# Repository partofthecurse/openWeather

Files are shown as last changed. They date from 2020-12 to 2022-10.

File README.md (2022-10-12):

# openWeather
Open Source Weather Station that also looks quite nice.
Concept:
We are requesting Temperature and Weather ID with an openWeatherMap API Call . Weather is Displayed through Neopixel LEDs under a PMMA-Screen with engraved Icons. Temperature is resembled with LED Colour.

Features:
    - MQTT
    - ArduinoOTA
    - WifiManager & Captive Portal

Parts needed:

    - ESP8266 or ESP32 Board, alternatively arduino nano with wifi shield will do as well but not coded here
    - Optional: DHT22 or DHT11 Sensor to measure Indoor Temp and Humidity
    - 4x WS2812 (aka NeoPixel) LED

Solder the 4 LEDs into a tiny LED Strip and connect to Dev Board:

    Board LED   LED   LED   LED
    3V3 - VCC - VCC - VCC - VCC
    GND - GND - GND - GND - GND
    D8 -  I/0 - I/O - I/O - I

Connect DHT22 / DHT11 to

    Board DHT
    3V3 - +
    GND - -
    D4  - OUT

Pixel-ID Icon reference (take care when assembling or switch in the code)

    0 - clear sky
    1 - cloudy
    2 - rainy
    3 - snow

Outdoortemperature & Colours:

    > 30°C - Red
    > 21°C - Warm yellow
    < 18°C - Light blue
    < 00°C - Blue
    Thunderstorm: Yellow
    Fog: White

    Red: error
    green: connecting

Optional: Send the measured DHT Data to an MQTT Broker (topics are customizable in captive portal)
    
    receive Data:
    temperature: stat/openWeather/Temperatur
    Humidity: stat/openWeather/Feuchtigkeit
    HeatIndex: stat/openWeather/HeatIndex
    
    controll openWeather:
    light on: cmnd/openWeather/power - payload on
    light off: cmnd/openWeather/power - payload off
    switch to party mode: cmnd/openWeather/state - PixelParty1 or PixelParty2
    
    upon receiving a command it sends back on stat/openWeather/power and stat/openWeather/state which mode it is in.
    
Dependencies:

    PubSubClient
    ArduinoJson
    ESP8266 Libs
    ESP32 Libs
    DHT Sensor library for ESPx
    WifiManager
    LittleFS
    
Now with WifiManager and OTA Updates (PW: admin)

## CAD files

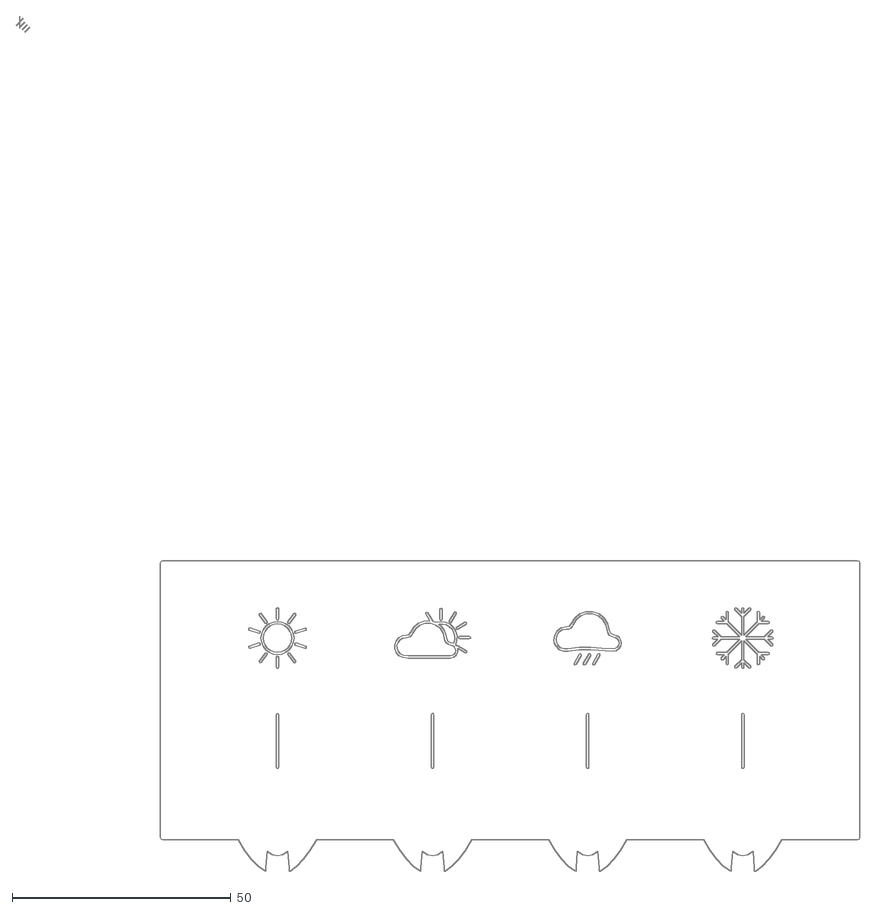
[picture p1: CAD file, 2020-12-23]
DXF/Scheibe1.DXF
192.7 x 195.3

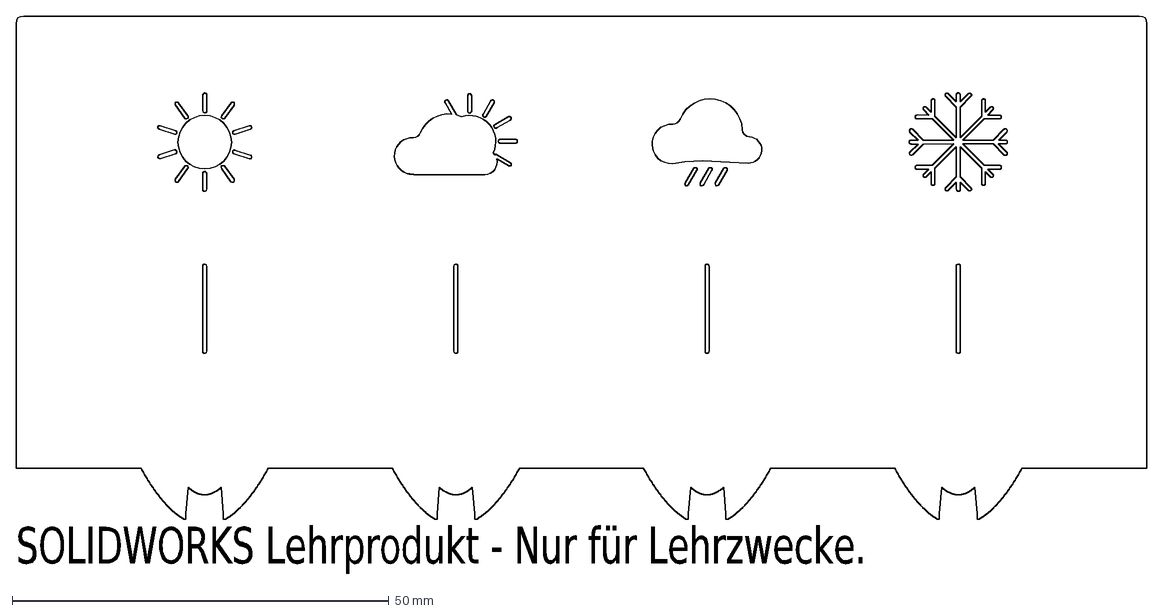
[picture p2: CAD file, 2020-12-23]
DXF/Scheibe.DXF
SOLIDWORKS Lehrprodukt - Nur für Lehrzwecke.

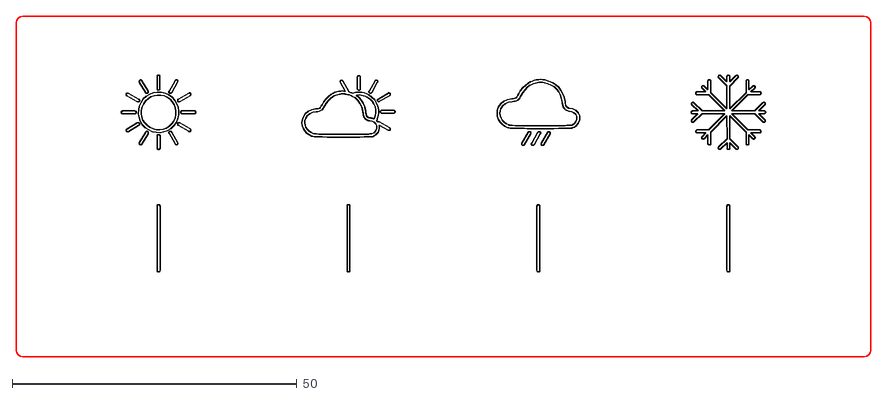
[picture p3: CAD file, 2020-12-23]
DXF/ICON_Design.dxf
150.0 x 59.8

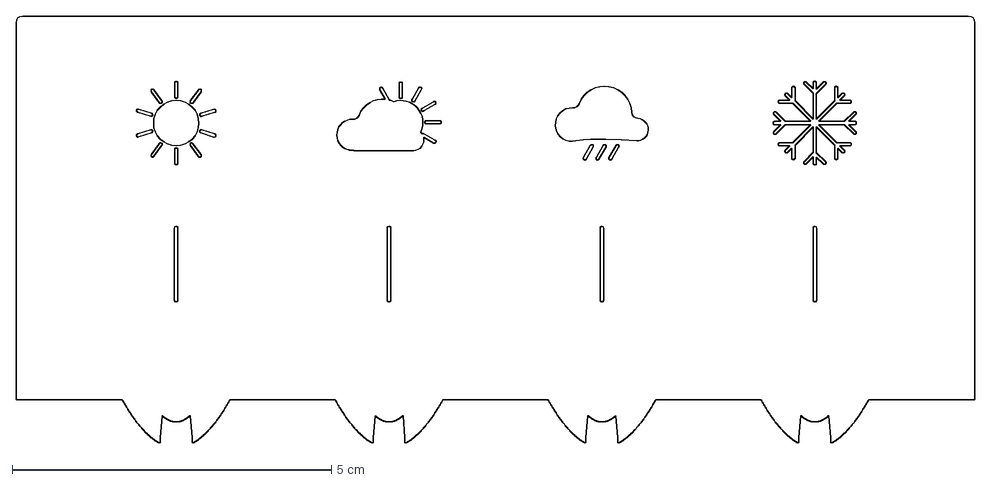
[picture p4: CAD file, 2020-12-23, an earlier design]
DXF/Scheibe v1.dxf
15.0 x 6.68 cm

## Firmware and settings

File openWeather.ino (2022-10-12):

/* Open Weather - the open source weatherbeacon that also looks good.
    We connect to your home wifi and send a http request to open weathermap every hour to update the free 3 hour forecast.
    depending on the weather-id (https://openweathermap.org/weather-conditions#Weather-Condition-Codes-2) another led will light up
    in a predefined colour to resemble weather and temperature and hightlight the respective icon.

    See Full documentation on https://daniel-strohbach.de/diy-esp8266-wetterstation

    Parts needed:
    - ESP8266 or ESP32 Board, alternatively arduino nano with wifi shield will do as well but not coded here
    - Optional: DHT22 or DHT11 Sensor to measure Indoor Temp and Humidity
    - 4x WS2812 (aka NeoPixel) LED

    Solder the 4 LEDs into a tiny LED Strip and connect to Dev Board:
    Board LED   LED   LED   LED
    3V3 - VCC - VCC - VCC - VCC
    GND - GND - GND - GND - GND
    D8 -  I/0 - I/O - I/O - I

    Connect DHT22 / DHT11 to
    Board DHT
    3V3 - +
    GND - -
    D4  - OUT

    Pixel-ID Icon reference (take care when assembling or switch in the code

    0 - clear sky
    1 - cloudy
    2 - rainy
    3 - snow

    Outdoortemperature & Colours:
    > 30°C - Red
    > 21°C - Warm yellow
    < 18°C - Light blue
    < 00°C - Blue
    Thunderstorm: Yellow
    Fog: White

    Red: Wifi related error
    green: connecting

    Optional: Send the measured DHT Data to an MQTT Broker (topics are customizable within captive portal)
    receive Data:
    temperature: stat/openWeather/Temperatur
    Humidity: stat/openWeather/Feuchtigkeit
    HeatIndex: stat/openWeather/HeatIndex
    
    control openWeather:
    light on: cmnd/openWeather/power - payload on
    light off: cmnd/openWeather/power - payload off
    switch to party mode: cmnd/openWeather/state - PixelParty1 or PixelParty2
    
    upon receiving a command it sends back on stat/openWeather/power and stat/openWeather/state which mode it is in.
    
    Dependencies:
    PubSubClient
    ArduinoJson
    ESP8266 Libs
    ESP32 Libs
    DHT Sensor library for ESPx
    WifiManager
    LittleFS

    Now with Wifi Manager or HardCoded Wifi credentials optional.
    Thanks to https://github.com/CurlyWurly-1/ESP8266-WIFIMANAGER-MQTT/blob/master/MQTT_with_WiFiManager.ino
    
    Now with OTA Update via ArduinoOTA

    Made By Daniel Strohbach www.daniel-strohbach.de/
*/

//--- USER CONFIG ---

//Do you want to use MQTT?
#define USEMQTT

//Do you want to use Managed WIFI or Hardcoded Wifi?
#define USEWIFIMANAGER
// #define USEWIFI //if so, do not forget to enter your credentials in line 116/117

//Do you want to use DHT?
#define USEDHT

//Do you use ESP8266 or ESP32? -> Switch to the correct one, if needed
#define ESP8266

//Do you want to use Serial Monitor for Debugging?
#define DEBUGING

//Which Board?

#ifdef ESP8266
#include <ESP8266WiFi.h>        // for WiFi functionality
#include <ESP8266HTTPClient.h>  //for the API-Request
#include <ESP8266WebServer.h>
//#include "SPIFFS.h"
#include <LittleFS.h>  //for ESP82
#define SPIFFS LittleFS
#endif

#ifdef ESP32
#include <WiFi.h>  //in case you are on esp32 we switch to this line
#include <HTTPClient.h>
#include <ESP32WebServer.h>
//#include "SPIFFS.h"
#include <LITTLEFS.h>  //for ESP32
#define SPIFFS LITTLEFS
#endif

//WIfi-Manager and Captive Portal
#include <DNSServer.h>
#include <WiFiManager.h>  // https://github.com/tzapu/WiFiManager

//OTA Updates
#include <ESP8266mDNS.h>
#include <WiFiUdp.h>
#include <ArduinoOTA.h>

//Colours and Position
int GcolourR, GcolourG, GcolourB, Gposition;

// Please Change to your WIFI-Credentials
#ifdef USEWIFI
const char* ssid = "SSID";
const char* password = "PW";
#endif

//What citiy you want to receive the weather from?
const char* city = "Munich,de";  //City and Country like this Oldenburg,de

//Here please add your Open Weathermap API Key from https://home.openweathermap.org/api_keys
#define openWeatherAPI "API"

//What units do you use?
const char* unitSystem = "metric";

#include <ArduinoJson.h>  //JSON String conversion for Open Weathermap API Request and WifiManager

// We use Neopixel to Control the WS2812. In my build i use a node mcu esp8266 and pin d8 to drive the pixels
#include <Adafruit_NeoPixel.h>

#define LEDPIN D8    //neopixels to pin d8
#define NUMPIXELS 4  // My Vesion has 4 Pixels

Adafruit_NeoPixel pixels(NUMPIXELS, LEDPIN, NEO_GRB + NEO_KHZ800);  //build the neopixel constructor

#ifdef USEWIFIMANAGER
WiFiManager wifiManager;
#endif

//--- MQTT ---
#ifdef USEMQTT
#include <PubSubClient.h>

bool mqttConnected = false;

//define your default values here, if there are different values in config.json, they are overwritten.
#define mqttServer "192.168.178.XX"
#define mqttUsername "mqtt-user"
#define mqttPassword "PW"
#define mqttPort "1883"
#define mqttDeviceID "openWeather"

//i use something quite similar to tasmota, but feel free to change
#define subTopic "cmnd/openWeather/state"
#define subTopic1 "cmnd/openWeather/power"
#define resTopic "stat/openWeather/state"
#define resTopic1 "stat/openWeather/power"
#define temperatureTopic "stat/openWeather/Temperatur"
#define humidityTopic "stat/openWeather/Feuchtigkeit"
#define heatIndexTopic "stat/openWeather/HeatIndex"

unsigned long lastMsg = 0;

WiFiClient openWeather;
PubSubClient MQTTclient(openWeather);
void callback(char* topic, byte* message, unsigned int length);
#endif

//--- DHT ---
#ifdef USEDHT
#include "DHTesp.h"
#define DHTPIN D4
DHTesp dht;

//--- Global Variables for Sensor storage--- // not elegant, but it works :)
float temperature, humidity, heatIndex;
#endif

//--- Timer Stuff ---
#ifdef USEDHT
unsigned long previousMillisMes;             //previous timer time
const unsigned long measureIntervall = 500;  //update sensor every 500ms
#endif

#ifdef USEMQTT
unsigned long previousMillisPub;              //for timer to publish to mqtt broker
const unsigned long publishIntervall = 5000;  //publish mqtt every 5 sekonds
#endif

unsigned long previousMillisReq;                 //for timer to request the weather data from openWeathermap
const unsigned long requestIntervall = 3600000;  //drive http request every hour

int modus = 0;          //for different control modes
bool firstloop = true;  //well, self explanatory

//flag for saving data
#ifdef USEWIFIMANAGER
bool shouldSaveConfig = false;
#endif

//---------------------------------------------- ARDUINO SETUP ------------------------------------------------------

void setup() {
  //Begin serial connection
#ifdef DEBUGING
  Serial.begin(9600);
  Serial.println();
  Serial.println();

  //Welcome to Serial Monitor
  Serial.println("openWeather: Erfasse Wetter, Temperatur, Feuchtigkeit on: ");
  String thisBoard = ARDUINO_BOARD;
  Serial.println(thisBoard);
#endif

  //--Neopixel
  pixels.begin();  // INITIALIZE NeoPixel strip object
  pixels.clear();  // Set all pixel colors to 'off'

#ifdef USEWIFIMANAGER
  //Wifi-Manager
  setup_wifimanager();
#endif

#ifdef USEWIFI
  //--Wifi
  setup_wifi();
#endif

  //--MQTT
#ifdef USEMQTT
  MQTTclient.setServer(mqttServer, atoi(mqttPort));
#ifdef DEBUGING
  Serial.println("MQTT Setup: Server and Port are Set to: ");
#endif
  MQTTclient.setCallback(callback);
#ifdef DEBUGING
  Serial.println("MQTT Setup: callback function set");
#endif
  MQTTclient.subscribe(subTopic);
#ifdef DEBUGING
  Serial.println("MQTT Setup: subscribed to subTopic");
#endif
  MQTTclient.setKeepAlive(90);
#ifdef DEBUGING
  Serial.println("MQTT Setup: set KeepAlive to 90");
#endif
  reconnect();  //establish connection to mqtt server
#ifdef DEBUGING
  Serial.println("MQTT Setup: finished");
#endif
#endif

  //--DHT
#ifdef USEDHT
  dht.setup(DHTPIN, DHTesp::DHT22);  // Connect DHT sensor to GPIO 17
#ifdef DEBUGING
  Serial.println("DHT Setup: Sensor connected to GPIO");
#endif
#endif

  //--OTA UPDATES

  // Port defaults to 8266
  // ArduinoOTA.setPort(8266);

  // Hostname defaults to esp8266-[ChipID]
  ArduinoOTA.setHostname("openWeather");

  // No authentication by default
  ArduinoOTA.setPassword("admin");

  // Password can be set with it's md5 value as well
  // MD5(admin) = 21232f297a57a5a743894a0e4a801fc3
  // ArduinoOTA.setPasswordHash("21232f297a57a5a743894a0e4a801fc3");

  ArduinoOTA.onStart([]() {
    String type;
    if (ArduinoOTA.getCommand() == U_FLASH) {
      type = "sketch";
    } else {  // U_FS
      type = "filesystem";
    }

// NOTE: if updating FS this would be the place to unmount FS using FS.end()
#ifdef DEBUGING
    Serial.println("Start updating " + type);
#endif
  });
  ArduinoOTA.onEnd([]() {
#ifdef DEBUGING
    Serial.println("\nEnd");
#endif
  });
  ArduinoOTA.onProgress([](unsigned int progress, unsigned int total) {
#ifdef DEBUGING
    Serial.printf("Progress: %u%%\r", (progress / (total / 100)));
#endif
  });
  ArduinoOTA.onError([](ota_error_t error) {
#ifdef DEBUGING
    Serial.printf("Error[%u]: ", error);
    if (error == OTA_AUTH_ERROR) {
      Serial.println("Auth Failed");
    } else if (error == OTA_BEGIN_ERROR) {
      Serial.println("Begin Failed");
    } else if (error == OTA_CONNECT_ERROR) {
      Serial.println("Connect Failed");
    } else if (error == OTA_RECEIVE_ERROR) {
      Serial.println("Receive Failed");
    } else if (error == OTA_END_ERROR) {
      Serial.println("End Failed");
    }
#endif
  });
  ArduinoOTA.begin();
}  // end of void setup

//--- ARDUINO LOOP ---

void loop() {

#ifdef DEBUGING
  Serial.println("void loop: Started... ");
  Serial.print("Wifi Connected: ");

  if ((WiFi.status() == WL_CONNECTED)) {
    Serial.println("true");
  } else {
    Serial.println("false");
  }
#ifdef USEMQTT
  Serial.print("MQTT Connected: ");
  if ((MQTTclient.state() == 0)) {
    Serial.println("true");
  } else {
    Serial.println("false");
  }
#endif
#endif

  ArduinoOTA.handle();  //handles the ota update stuff

//if mqtt is not connected, try again
#ifdef USEMQTT
  if ((!MQTTclient.state() == 0)) {
    reconnect();
  }
#endif

//what mode are we in? (light on or off, party mode or not)
#ifdef DEBUGING
  Serial.print("void loop: Modus: ");
  Serial.println(modus);
#endif

  //if we are in the first loop, we already want to fetch the weather data, afterwards only every hour
  if (firstloop) {
    getWeather();
    firstloop = false;
#ifdef DEBUGING
    Serial.print("first loop: fetching weather data: ");
#endif
  }

  //get Weatherdata every hour (or what you did custom)
  if (millis() - previousMillisReq >= requestIntervall) {
    previousMillisReq = millis();
    if (modus == 0) {
      getWeather();
#ifdef DEBUGING
      Serial.print("timer: fetching weather data: ");
#endif
    }
  }

//read sensor data
#ifdef USEDHT
  //read sensor
  if (millis() - previousMillisMes >= measureIntervall) {
    previousMillisMes = millis();
    getDHT();
#ifdef DEBUGING
    Serial.print("timer: fetching dht sensor data: ");
#endif
  }
#endif

//send the data to mqtt broker
#ifdef USEMQTT
  //publish to MQTT Broker
  if (millis() - previousMillisPub >= publishIntervall) {
    previousMillisPub = millis();
    publishMQTT();
#ifdef DEBUGING
    Serial.print("timer: sending mqtt data: ");
#endif
  }
#endif

//keep mqtt connection alive
#ifdef USEMQTT
  if (MQTTclient.loop()) {
#ifdef DEBUGING
    Serial.println("MQTT Client.loop called successfull");
#endif
  } else {
#ifdef DEBUGING
    Serial.println("MQTT Client.loop call failed");
#endif
  }
#endif

  //some remote control for different uses - maybe switch case is better?!
  if (modus == 1) {
    pixelParty();
  }

  if (modus == 2) {
    rainbowFade(3, 3, 1);
  }

  if (modus == 3) {  //weather icon is off
    pixels.clear();
    pixels.show();
  }

  if (modus == 0) {  // weather icon is on again
    pixels.clear();
    showWeather();
  }

}  //end of void loop

//--- CUSTOM CLASSES ---

//--callback notifying us of the need to save config
void saveConfigCallback() {
#ifdef DEBUGING
  Serial.println("Should save config");
#endif
  shouldSaveConfig = true;
}

//------------------------Wifi-Manager-----------------------------
#ifdef USEWIFIMANAGER
void setup_wifimanager() {

//clean FS for testing
//  SPIFFS.format();

//read configuration from FS json
#ifdef DEBUGING
  Serial.println("Using Wifi Manager");
  Serial.println("mounting FS...");
#endif

  if (SPIFFS.begin()) {
#ifdef DEBUGING
    Serial.println("mounted file system");
#endif
    if (SPIFFS.exists("/config.json")) {
//file exists, reading and loading
#ifdef DEBUGING
      Serial.println("reading config file");
#endif
      File configFile = SPIFFS.open("/config.json", "r");
      if (configFile) {
#ifdef DEBUGING
        Serial.println("opened config file");
#endif
        size_t size = configFile.size();
        // Allocate a buffer to store contents of the file.
        std::unique_ptr<char[]> buf(new char[size]);

        configFile.readBytes(buf.get(), size);
        DynamicJsonDocument doc(2048);
        deserializeJson(doc, buf.get());
        auto error = serializeJson(doc, Serial);
        if (!error) {
#ifdef DEBUGING
          Serial.println("\nparsed json");
#endif
          strcpy(mqttServer, doc["mqttServer"]);
          strcpy(mqttPort, doc["mqttPort"]);
          strcpy(mqttUsername, doc["mqttUsername"]);
          strcpy(mqttPassword, doc["mqttPassword"]);
          strcpy(mqttDeviceID, doc["mqttDeviceID"]);
          strcpy(openWeatherAPI, doc["openWeatherAPI"]);
          strcpy(subTopic, doc["subTopic"]);
          strcpy(subTopic1, doc["subTopic1"]);
          strcpy(resTopic, doc["resTopic"]);
          strcpy(resTopic1, doc["resTopic1"]);
          strcpy(temperatureTopic, doc["temperatureTopic"]);
          strcpy(humidityTopic, doc["humidityTopic"]);
          strcpy(heatIndexTopic, doc["heatIndexTopic"]);

        } else {
#ifdef DEBUGING
          Serial.println("failed to load json config");
#endif
        }
      }
    }
  } else {
#ifdef DEBUGING
    Serial.println("failed to mount FS");
#endif
  }
  //end read

  // The extra parameters to be configured (can be either global or just in the setup)
  // After connecting, parameter.getValue() will get you the configured value
  // id/name placeholder/prompt default length
  WiFiManagerParameter custom_mqttServer("server", "mqtt server", mqttServer, 100);
  WiFiManagerParameter custom_mqttPort("port", "mqtt port", mqttPort, 20);
  WiFiManagerParameter custom_mqttUsername("user", "mqtt user", mqttUsername, 100);
  WiFiManagerParameter custom_mqttPassword("pass", "mqtt pass", mqttPassword, 100);
  WiFiManagerParameter custom_mqttDeviceID("deviceID", "mqtt deviceid", mqttDeviceID, 100);
  WiFiManagerParameter custom_openWeatherAPI("API", "openWeather API", openWeatherAPI, 160);

  WiFiManagerParameter custom_subTopic("Sub", "Sub Topic", subTopic, 100);
  WiFiManagerParameter custom_subTopic1("Sub1", "Sub Topic1", subTopic1, 100);
  WiFiManagerParameter custom_resTopic("res", "Res Topic", resTopic, 100);
  WiFiManagerParameter custom_resTopic1("res1", "Res Topic1", resTopic1, 100);
  WiFiManagerParameter custom_temperatureTopic("temp", "Temperature Topic", temperatureTopic, 100);
  WiFiManagerParameter custom_humidityTopic("humid", "Humidity Topic", humidityTopic, 100);
  WiFiManagerParameter custom_heatIndexTopic("HI", "Heat Index Topic", heatIndexTopic, 100);

  //Wifi-Manager
  WiFiManager wifiManager;
  //wifiManager.autoConnect("openWeather-AP");

  //Reset Wifi settings for testing
  // wifiManager.resetSettings();

  //set config save notify callback
  wifiManager.setSaveConfigCallback(saveConfigCallback);

  //add all your parameters here
  wifiManager.addParameter(&custom_mqttServer);
  wifiManager.addParameter(&custom_mqttPort);
  wifiManager.addParameter(&custom_mqttUsername);
  wifiManager.addParameter(&custom_mqttPassword);
  wifiManager.addParameter(&custom_mqttDeviceID);
  wifiManager.addParameter(&custom_openWeatherAPI);
  wifiManager.addParameter(&custom_subTopic);
  wifiManager.addParameter(&custom_subTopic1);
  wifiManager.addParameter(&custom_resTopic);
  wifiManager.addParameter(&custom_resTopic1);
  wifiManager.addParameter(&custom_temperatureTopic);
  wifiManager.addParameter(&custom_humidityTopic);
  wifiManager.addParameter(&custom_heatIndexTopic);



  //reset settings - for testing
  // wifiManager.resetSettings();

  //set minimum quality of signal so it ignores AP's under that quality
  //defaults to 8%
  //wifiManager.setMinimumSignalQuality();

  //sets timeout until configuration portal gets turned off
  //useful to make it all retry or go to sleep
  //in seconds
  //wifiManager.setTimeout(120);
  //little animation to signal whats going on

  //Signal wifi connecting with green animation
  for (int i = 0; i < NUMPIXELS; i++) {  // For each pixel...

    // pixels.Color() takes RGB values, from 0,0,0 up to 255,255,255
    // Here we're using a moderately bright green color:
    pixels.setPixelColor(i, pixels.Color(0, 255, 0));

    pixels.show();  // Send the updated pixel colors to the hardware.

    delay(500);  // Pause before next pass through loop
  }


  //fetches ssid and pass and tries to connect
  //if it does not connect it starts an access point with the specified name
  //and goes into a blocking loop awaiting configuration
  if (!wifiManager.autoConnect("openWeather-Accesspoint")) {
#ifdef DEBUGING
    Serial.println("failed to connect and hit timeout");
#endif
    delay(3000);
    //reset and try again, or maybe put it to deep sleep
    ESP.reset();
    delay(5000);
  }

//if you get here you have connected to the WiFi
#ifdef DEBUGING
  Serial.println("connected to wifi: ");
#endif
  //read updated parameters
  strcpy(mqttServer, custom_mqttServer.getValue());
  strcpy(mqttPort, custom_mqttPort.getValue());
  strcpy(mqttUsername, custom_mqttUsername.getValue());
  strcpy(mqttPassword, custom_mqttPassword.getValue());
  strcpy(mqttDeviceID, custom_mqttDeviceID.getValue());
  strcpy(openWeatherAPI, custom_openWeatherAPI.getValue());

  strcpy(subTopic, custom_subTopic.getValue());
  strcpy(subTopic1, custom_subTopic1.getValue());
  strcpy(resTopic, custom_resTopic.getValue());
  strcpy(resTopic1, custom_resTopic1.getValue());
  strcpy(temperatureTopic, custom_temperatureTopic.getValue());
  strcpy(humidityTopic, custom_humidityTopic.getValue());
  strcpy(heatIndexTopic, custom_heatIndexTopic.getValue());

  //save the custom parameters to FS
  if (shouldSaveConfig) {
#ifdef DEBUGING
    Serial.println("saving config: ");
#endif

    DynamicJsonDocument json(2048);

    json["mqttServer"] = mqttServer;
    json["mqttPort"] = mqttPort;
    json["mqttUsername"] = mqttUsername;
    json["mqttPassword"] = mqttPassword;
    json["mqttDeviceID"] = mqttDeviceID;
    json["openWeatherAPI"] = openWeatherAPI;

    json["subTopic"] = subTopic;
    json["subTopic1"] = subTopic1;
    json["resTopic"] = resTopic;
    json["resTopic1"] = resTopic1;
    json["temperatureTopic"] = temperatureTopic;
    json["humidityTopic"] = humidityTopic;
    json["heatIndexTopic"] = heatIndexTopic;

    File configFile = SPIFFS.open("/config.json", "w");
    if (!configFile) {
#ifdef DEBUGING
      Serial.println("failed to open config file for writing");
#endif
    }

    serializeJson(json, Serial);
    serializeJson(json, configFile);
    configFile.close();
    //end save
  }
#ifdef DEBUGING
  Serial.print("local ip: ");
  Serial.println(WiFi.localIP());
#endif
}
#endif

//--------------------------------------------Wifi------------------------------------
#ifdef USEWIFI
void setup_wifi() {
#ifdef DEBUGING
  Serial.println("setup_wifi: Started... ");
  delay(10);
  // We start by connecting to a WiFi network
  Serial.println();
  Serial.print("Connecting to: ");
  Serial.println(ssid);
#endif

  WiFi.mode(WIFI_STA);
  WiFi.begin(ssid, password);

  //Signal wifi connecting with green animation
  for (int i = 0; i < NUMPIXELS; i++) {  // For each pixel...

    // pixels.Color() takes RGB values, from 0,0,0 up to 255,255,255
    // Here we're using a moderately bright green color:
    pixels.setPixelColor(i, pixels.Color(0, 255, 0));

    pixels.show();  // Send the updated pixel colors to the hardware.

    delay(500);  // Pause before next pass through loop
  }


#ifdef DEBUGING
  Serial.println("");
  Serial.println("WiFi connected");
  Serial.println("IP address: ");
  Serial.println(WiFi.localIP());
#endif
}
#endif

//----------------------------------- RECONNECT MQTT ---------------------
#ifdef USEMQTT
void reconnect() {
  // Loop until we're reconnected

#ifdef DEBUGING
  Serial.println("MQTT reconnect: ");
#endif
  int errorcounter = 0;

  while (!MQTTclient.connected()) {
#ifdef DEBUGING
    Serial.println("MQTT reconnect: Attempting MQTT connection...");
    Serial.println("Credentials:");
    Serial.print("MQTT Server: ");
    Serial.println(mqttServer);
    Serial.print("MQTT Port: ");
    Serial.println(mqttPort);
    Serial.print("MQTT Username: ");
    Serial.println(mqttUsername);
    Serial.print("MQTT Password: ");
    Serial.println(mqttPassword);
    Serial.print("MQTT DeviceID: ");
    Serial.println(mqttDeviceID);
#endif

    //connection animation - did cause some errors
    // pixels.clear();
    // for (int i = 0; i < NUMPIXELS; i++) {  // For each pixel...

    //   // pixels.Color() takes RGB values, from 0,0,0 up to 255,255,255
    //   // Here we're using a moderately bright green color:
    //   pixels.setPixelColor(i, pixels.Color(0, 0, 255));

    //   pixels.show();  // Send the updated pixel colors to the hardware.

    //   delay(500);  // Pause before next pass through loop
    // }


    // Attempt to connect
    if (MQTTclient.connect(mqttDeviceID, mqttUsername, mqttPassword)) {
      mqttConnected = true;
      //keep alive
      MQTTclient.loop();

      //connect callback function
      MQTTclient.setCallback(callback);
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

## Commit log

2022-10-09 Update openWeather.ino
    Fixed syntax Errors with new version,
    fixed mqtt callback error
    switched mqtt channels
    [openWeather.ino]
2022-10-10 Update openWeather.ino
    fixed a typo
    [openWeather.ino]
2022-10-11 Update openWeather.ino
    fixed copy&paste error in topics
    [openWeather.ino]
2022-10-11 Update openWeather.ino
    changed reset conditions for esp reset when unable to connect to mqtt server
    [openWeather.ino]
2022-10-12 Update openWeather.ino
    included ArduinoOTA
